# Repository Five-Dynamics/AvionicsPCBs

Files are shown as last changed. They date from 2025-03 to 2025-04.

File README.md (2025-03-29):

# Avionics PCB
All KICAD pcb Files for the electrical system

To contribute:

- Open/select Issue, assign yourself to it, add labels/milestones
- Create new branch and make changes
- Open Pull Request when ready (not too many big big changes or hard to review)
- Fill out the PR form, assign it to yourself, add labels/milestones, LINK PR TO ISSUE, which will autoclose it
- Make sure it passes all automated tests/formatting/shanking
- Request your reviewers

Make changes if needed (changes requested from reviewers)

Once all approved, merge by yourself.

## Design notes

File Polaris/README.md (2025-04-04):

# COMPONENT SPECS

## MICROCONTROLLER SPECS
Name: STM32H755XIH6

[Datasheet](https://www.st.com/resource/en/datasheet/stm32h755bi.pdf)
[Info](https://www.st.com/resource/en/application_note/an4938-getting-started-with-stm32h74xig-and-stm32h75xig-mcu-hardware-development-stmicroelectronics.pdf)

Voltage required: 3.3V

Total source current: 620mA

Total pin output current: 140mA

Clock Frequency: 64MHz

Communication method: SPI, SDIO

## BAROMETER SPECS
Name: MS5611

[Datasheet](https://www.te.com/commerce/DocumentDelivery/DDEController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)

Voltage required: 3.3V

Current rating: 1.4mA

Communication method: SPI, using channel 3
## IMU SPECS
Name: Adafruit ISM330DHCX

[Datasheet](https://www.st.com/resource/en/datasheet/ism330dhcx.pdf)

Voltage rating: Typical 1.8V, max rating 3.6V

Current consumption: 1.5mA

Communication method: SPI, using channels 2 & 5

## ON BOARD FLASH
Name: SST25VF080B

[Datasheet](http://ww1.microchip.com/downloads/en/DeviceDoc/20005045C.pdf)

Voltage: 2.7V ~ 3.6V

Current rating: 10mA max

Data Size: 1MB

Communication method: SPI, using channels 4
## SD CARD SPECS
Name: Adafruit Micro SD SPI or SDIO Card

[Datasheet](https://cdn-learn.adafruit.com/downloads/pdf/adafruit-microsd-spi-sdio.pdf)

Voltage: 3.3V

Communication method: SDIO *Pin not assigned yet
## GPS SPECS
Name: NEO-M8M

[Datasheet](https://content.u-blox.com/sites/default/files/products/documents/NEO-M8_ProductSummary_UBX-16000345.pdf)

## RADIO SPECS
Name: Adafruit RFM95W LoRa Radio

[Info](https://www.adafruit.com/product/3072)

Bit rate: 300 kbps

current consumption: 10.3mA

Communication method: SPI, using channel 6.
## SERVO SPECS
Name: DS5160

[Datasheet](https://m.media-amazon.com/images/I/81EFGw8qkhL.pdf)

Voltage rating: 8V

Current consumption: 6.2A

Note: requires PWM to control it
## BATTERY SPECS 1
Name: GRP402049-1C-3.8V-450mAh

[Datasheet](https://drive.google.com/file/d/1r1or5fdFM2Az3-8GFAZaegb-1_r7XS7f/view)

Note: Selected for being Lipo, which lab comes with Lipo charger & resistence to vibration
## BATTERY SPECS 2
Name: GRP403530-1C-4.35V-360mAh with PCM

[Datasheet](https://drive.google.com/file/d/1zsI7abhJyncET1ZgONkUpj0koPwNgk_m/view)

Note: For powering the Servo, which requires 8V, put 2 of them in series to create 8V. Selected for being Lipo, which lab comes with Lipo charger & resistence to vibration
## LDR SPECS
Undecided
## VOLTAGE RECTIFIER 1
Name: HT7533-1

[Datasheet](http://www.e-ele.net/DataSheet/HT75XX-1.pdf)

 Linear regulator for 3.3V, creating the needed voltage for most components
## VOLTAGE RECTIFIER 2
Name: UA78L08

[Datasheet](https://www.ti.com/lit/ds/symlink/ua78l.pdf?ts=1743278162471&ref_url=https%253A%252F%252Fwww.google.com%252F)

 Linear regulator for 3.3V, creating the needed voltage for the Servo
# PIN CONFIGURATION
## SPI Device Pin Assignments

| **SPI**  | **Device** | **MOSI** | **MISO** | **CLK** | **CS**  |
|---|---|---|---|---|---|
| **SPI1** | GPS | PA7 | PA6 | PA5  | PA4 |
| **SPI2** | IMU2 | PC1 | PC2_C | PB10 | PC3_C |
| **SPI3** | Barometer | PB2 | PC11 | PC10 | PC12  |
| **SPI4** | Memory Flash | PE6 | PE5 | PE2  | PE4 |
| **SPI5** | IMU1 | PF9 | PF8 | PF7  | PF6 |
| **SPI6** | Radio | PG14 | PG12 | PG13 | PG11 |
##

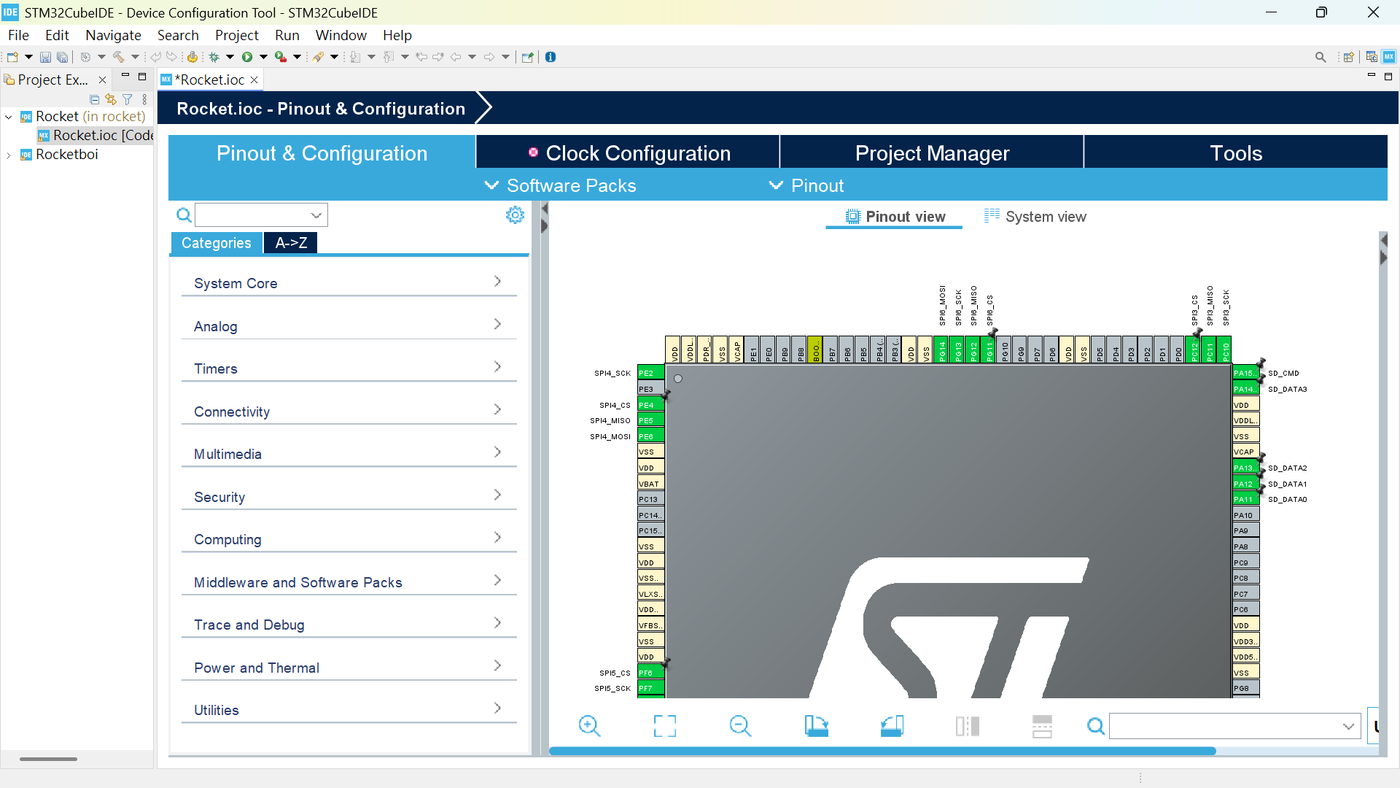
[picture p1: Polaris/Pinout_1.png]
Pinout1

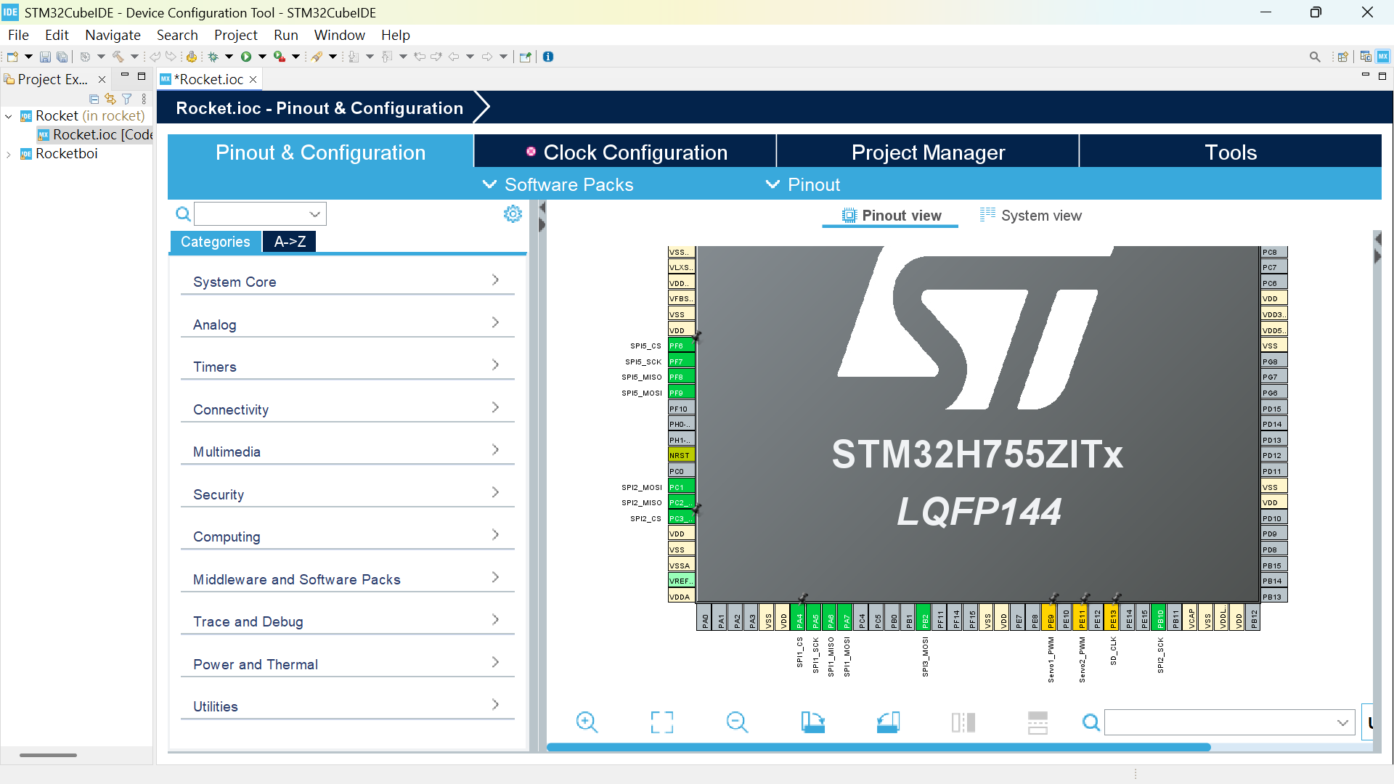
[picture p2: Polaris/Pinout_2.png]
Pinout2


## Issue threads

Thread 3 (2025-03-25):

Repository Revision Setup

darint916, 2025-03-25:
Change first design folder to rocket name of:
polaris.

Fix the readme:
erase bracket text in 2nd point

remove png images from design, add a README.md to the design to replace documentation on docs.

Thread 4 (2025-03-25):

SD Card Reading Issue, maybe onboard

darint916, 2025-03-25:
Concerns dataloss:
https://www.reddit.com/r/rocketry/comments/td4xe8/what_orientation_is_best_for_a_microsd_breakout/

Need recalculation on Approximate data throughout entire flight, need flight duration. Every sensor output speed. Need solder on flash memory as a buffer.

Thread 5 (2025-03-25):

Initialize Schematic Review and Documentation

darint916, 2025-03-25:
this might help in starting hierarchal schematic drafting, I think stm on highest level, big peripherals will be hierarchal:
https://embeddedcomputing.com/technology/analog-and-power/kicad-hierarchical-sheets-for-enhanced-schematics.

Need button battery backup. 3.3 v button battery to VBAT as backup + need holder.

Check Battery specification for lithium ion 12V, if so, need linear regulator to go down to 3.3, 8v

Check if all parts have components on digiekey or any other seller, and then link in documentation.
Link explicitly peripheral datasheets and location to check circuitry.
Link explicitly and show PCB Design Suggestion pages on the datasheets. or example circuits.
Make sure footprint correlates to buying part for smt/throughhole make sure solderable by hand.

Get max overall board constraints and drill hole specifications.

 Peripherals:
Move decoupling capacitors, closer on schematic to parts needing them

Download STM32IDE to check pin references (every pin on stm32ide, show all connections and ss if possible on pr)
Check PWM pins

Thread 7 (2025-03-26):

GPS and Radio Module Decision + connectors

darint916, 2025-03-26:
Revise excel sheet and decide which ones to buy, add connectors for each respective part if they're external.

I believe the GPS might have a mount that we can do , board on board mount? is this solderable connection mount? or does it use cables, if so, can we just migrate it to our board. Check for antenna specs.

Radio, if it is too complicated can be fully external and just wire, make sure they are reliable connectors, we could hijack up some vga connectors?

Need to look into asap.

Closed 2025-04-04.

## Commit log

2025-03-22 Rename 螢幕擷取畫面 2025-03-22 175850.png to Barometer
2025-03-22 Rename 螢幕擷取畫面 2025-03-22 175955.png to IMU
2025-03-22 Rename 螢幕擷取畫面 2025-03-22 180002.png to SDcard
2025-03-22 Rename 螢幕擷取畫面 2025-03-22 180008.png to Servo
2025-03-22 Rename 螢幕擷取畫面 2025-03-22 180015.png to Voltage regulator
2025-03-22 Rename 螢幕擷取畫面 2025-03-22 180022.png to decoupling capacitors
2025-03-22 Rename 螢幕擷取畫面 2025-03-22 180031.png to STM_1
2025-03-22 Rename 螢幕擷取畫面 2025-03-22 180045.png to STM_2
2025-03-22 Rename 螢幕擷取畫面 2025-03-22 180053.png to STM_3
2025-03-22 Rename Voltage regulator to voltage_regulator
2025-03-22 Rename decoupling capacitors to decoupling_capacitors
2025-03-23 Add files via upload
    KiCAD schematic file
    [Rocket.kicad_sch]
2025-03-29 folder name change
    [Rocket.kicad_sch]
2025-03-30 Update and rename Rocket.kicad_sch to Polaris/Rocket_01.kicad_sch
    [Rocket_01.kicad_sch]
2025-04-02 added print for erc errors
2025-04-03 Rename 螢幕擷取畫面 (1).png to Pinout_1.png
2025-04-03 Rename 螢幕擷取畫面 (2).png to Pinout_2.png
